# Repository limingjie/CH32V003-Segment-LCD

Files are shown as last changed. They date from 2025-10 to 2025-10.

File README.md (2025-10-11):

# CH32V003 3-Digit 7-Segment LCD Driver

The solution provides an efficient segment LCD driver for the low-cost CH32V003 microcontroller, capable of driving a TN Positive 3-digit 7-Segment LCD using minimal hardware resources and optimized firmware.

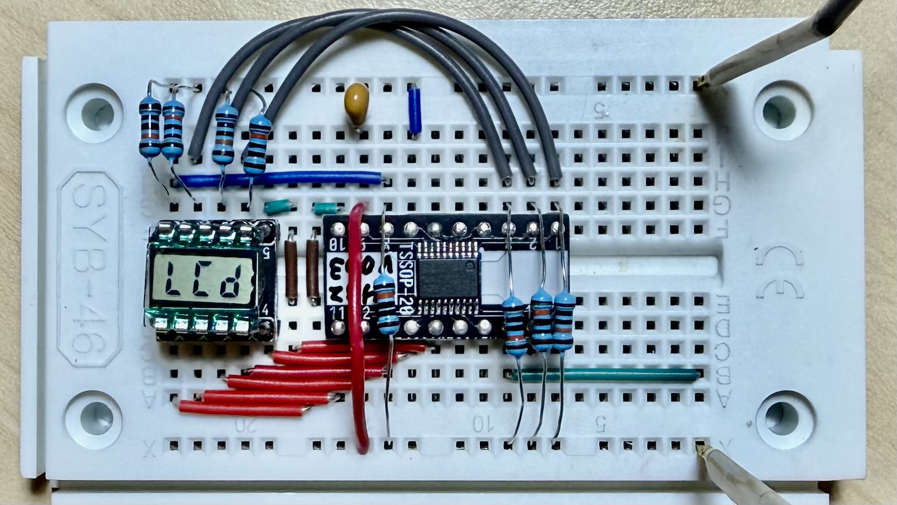
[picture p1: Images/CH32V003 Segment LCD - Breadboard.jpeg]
Breadboard


- [CH32V003 3-Digit 7-Segment LCD Driver](#ch32v003-3-digit-7-segment-lcd-driver)
  - [LCD Control Theory](#lcd-control-theory)
    - [LCD Multiplex](#lcd-multiplex)
    - [LCD Driver Signal and Timing](#lcd-driver-signal-and-timing)
  - [CH32V003 Implementation](#ch32v003-implementation)
    - [Circuit Design and Schematic](#circuit-design-and-schematic)
    - [Character Encoding and Mapping](#character-encoding-and-mapping)
    - [Driver Logic](#driver-logic)
  - [7-Segment Display Characters](#7-segment-display-characters)
  - [Hardware](#hardware)
    - [MCU - CH32V003](#mcu---ch32v003)
    - [TN Positive 3-Digit 7-Segment LCD Panel](#tn-positive-3-digit-7-segment-lcd-panel)
      - [Specifications](#specifications)
  - [References](#references)
  - [License](#license)

## LCD Control Theory

### LCD Multiplex

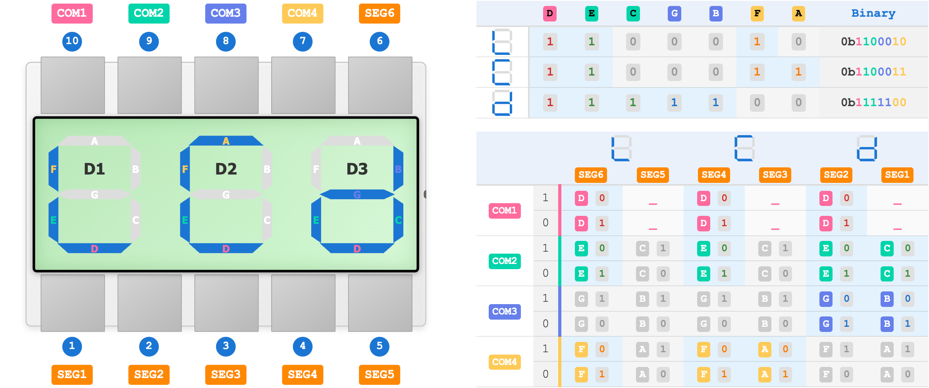
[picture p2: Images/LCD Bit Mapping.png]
LCD Bit Mapping


- Each Common pin controls 1 or 2 segments across 3 characters.
  - **`Common Pin 1`** - **`D`** segments.
  - **`Common Pin 2`** - **`E`** and **`C`** segments.
  - **`Common Pin 3`** - **`G`** and **`B`** segments.
  - **`Common Pin 4`** - **`F`** and **`A`** segments.
- Each Segment pin controls 3 or 4 segments within 1 character.
  - **`D1`** - **`Segment Pin 6`** (**`D`** **`E`** **`G`** **`F`**) and **`Segment Pin 5`** (**`C`** **`B`** **`A`**).
  - **`D2`** - **`Segment Pin 4`** (**`D`** **`E`** **`G`** **`F`**) and **`Segment Pin 3`** (**`C`** **`B`** **`A`**).
  - **`D3`** - **`Segment Pin 2`** (**`D`** **`E`** **`G`** **`F`**) and **`Segment Pin 1`** (**`C`** **`B`** **`A`**).

The wiring diagram of the LCD display (from [Pacific Display](https://www.pacificdisplay.com/lcd_multiplex_drive.htm)).

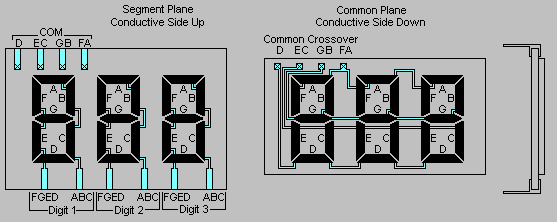
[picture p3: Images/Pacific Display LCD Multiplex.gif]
LCD Multiplex


### LCD Driver Signal and Timing

LCDs use AC signals to prevent damage and ensure longevity by avoiding DC-induced charge accumulation, which can permanently polarize and degrade liquid crystal molecules.

For a `1/2` bias LCD, the Common pins require 3 voltages: `+V`, `+V/2`, and `0`. Use the following timing sequence to ensure the average voltage across the LCD is `0`.

The matrix below shows the voltage difference `SEG - COM` for all possible voltage combinations. The LCD segment is lit when the voltage difference is exactly `±V`.

- LCD segments are **Lit** when `SEG - COM = ±V` for `1/4` duty cycle.
- The voltage difference alternates between positive and negative to maintain AC operation

| **COM Voltages** | **`0` / `LOW`** | **`+V/2` / `FLOAT`** | **`+V`/`HIGH`** |
| :--- | ---: | ---: | ---: |
| **SEG Voltage =  `0` / `LOW`**  | `0` | `-V/2` |  (**Lit**) `-V` |
| **SEG Voltage = `+V` / `HIGH`** |  (**Lit**) `+V` | `+V/2` | `0` |

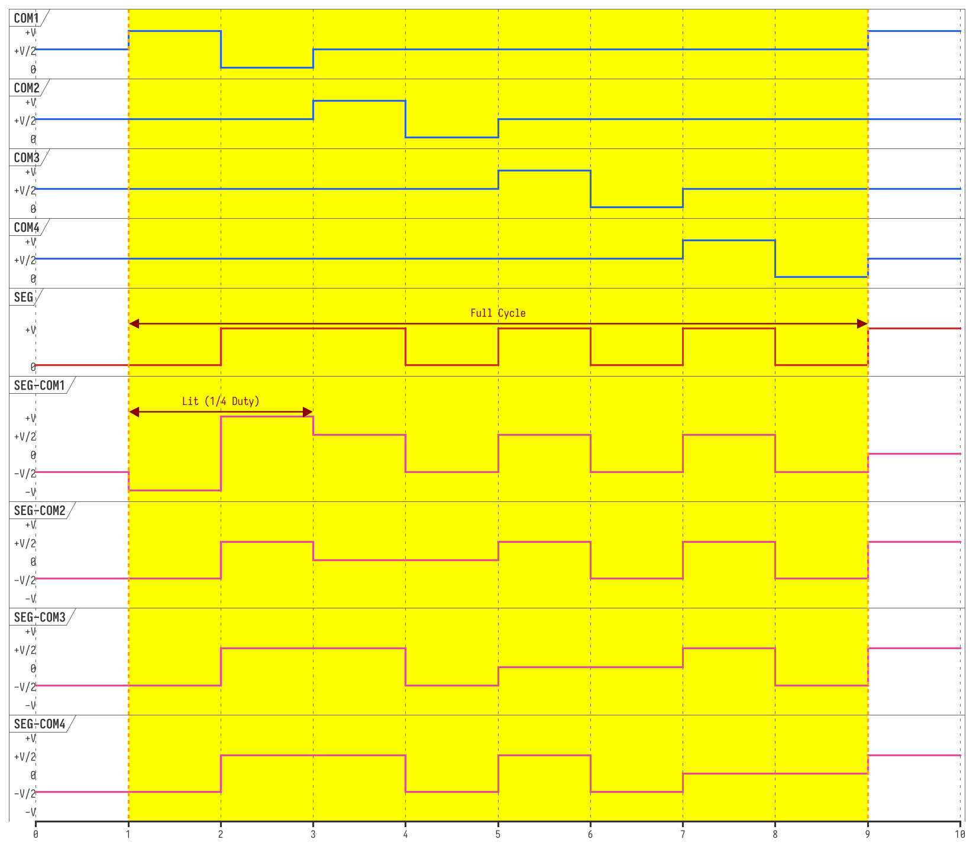
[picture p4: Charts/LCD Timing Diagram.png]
LCD Timing Diagram


## CH32V003 Implementation

### Circuit Design and Schematic

Each Common pin of the LCD is connected to an external voltage divider circuit. When the corresponding GPIO is set to floating input mode, the external voltage divider maintains the Common pin at `+V/2`.

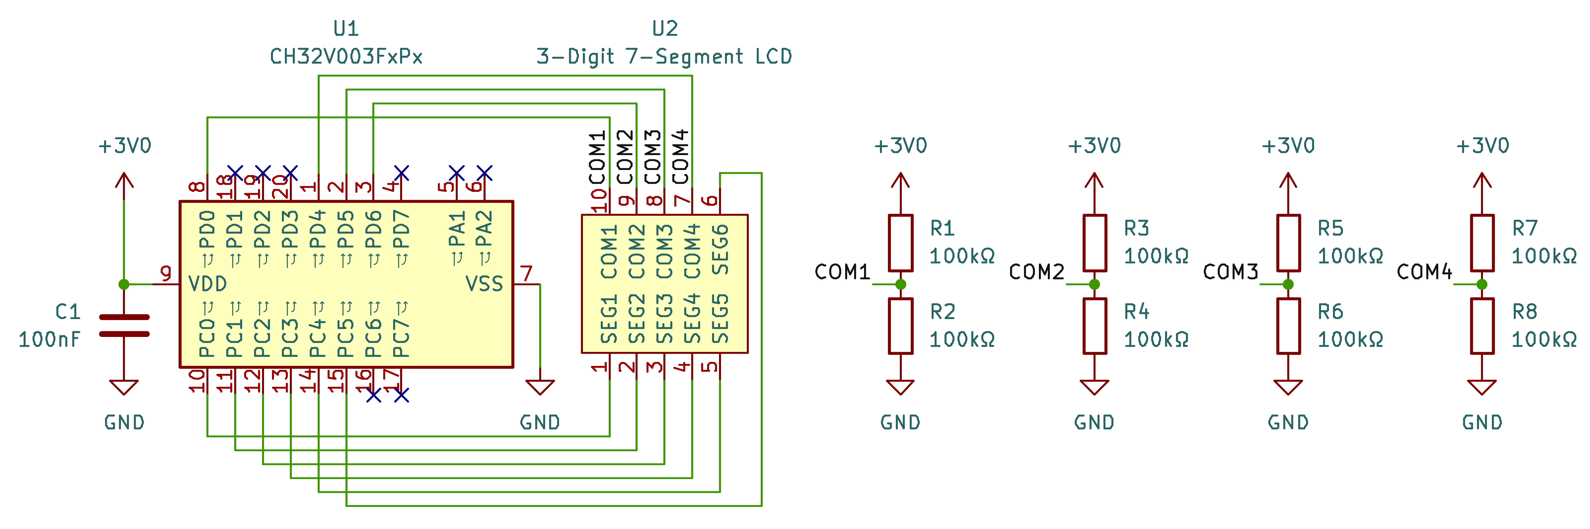
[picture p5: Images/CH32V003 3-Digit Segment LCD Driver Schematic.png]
CH3SchematicV003


### Character Encoding and Mapping

To simplify the 7-segment character to LCD multiplex conversion, the 7-segment character is encoded in **`0b D EC GB FA`**. Actually, any bit order works, keeping **`EC`** **`GB`** **`FA`** groups could simplify the bit operations.

Use the following code to calculate the segment values for each Common pin.

```C
// Convert Character Bit Order (0bDECGBFA) to Segment Masks for Each Common Pin
//                         LCD Char | Seg Group Mask   | <<Shifts>>
//                         D1 D2 D3 | 0bDECGBFA        | D1  D2  D3
// Segment Mask for COM1 - D_ D_ D_ - 0b1000000 / 0x40 - >>1 >>3 >>5
// Segment Mask for COM2 - EC EC EC - 0b0110000 / 0x30 -     >>2 >>4
// Segment Mask for COM3 - GB GB GB - 0b0001100 / 0x0C - <<2     >>2
// Segment Mask for COM4 - FA FA FA - 0b0000011 / 0x03 - <<4 <<2
//              Segments - 65 43 21
seg_masks[0] = ((d1_segs & 0x40) >> 1) | ((d2_segs & 0x40) >> 3) | ((d3_segs & 0x40) >> 5);  // COM1: D  bits
seg_masks[1] = ((d1_segs & 0x30) >> 0) | ((d2_segs & 0x30) >> 2) | ((d3_segs & 0x30) >> 4);  // COM2: EC bits
seg_masks[2] = ((d1_segs & 0x0C) << 2) | ((d2_segs & 0x0C) >> 0) | ((d3_segs & 0x0C) >> 2);  // COM3: GB bits
seg_masks[3] = ((d1_segs & 0x03) << 4) | ((d2_segs & 0x03) << 2) | ((d3_segs & 0x03) >> 0);  // COM4: FA bits
```

Instead of setting each pin individually, the segment values can be directly assigned to the entire GPIO port for more efficient operation.

```C
// BSHR upper 16 bits: Reset pins PC5-PC0 where mask bit = 0
// BSHR lower 16 bits: Set   pins PC5-PC0 where mask bit = 1
GPIOC->BSHR = ((~seg_masks[i] & 0x3F) << 16) | seg_masks[i];
```

### Driver Logic

For CH32V003, each common pin is pulled up and down by resistors to create `+V/2`, and the timing can be implemented with the following code:

```C
static const uint8_t com_pins[4]  = {PIN_COM1, PIN_COM2, PIN_COM3, PIN_COM4};

...

while (1)
{
    // 1000ms / (4ms x 4) = 62.5 FPS
    for (uint8_t i = 0; i < 4; i++)
    {
        const uint8_t com_pin      = com_pins[i];
        const uint8_t seg_mask     = seg_masks[i];
        const uint8_t inv_seg_mask = ~seg_mask & 0x3F;  // Keep lower 6 bits for PC5-PC0

        // COM - Output
        funPinMode(com_pin, GPIO_Speed_2MHz | GPIO_CNF_OUT_PP);

        // COM - High, SEG1-6 - Low as required
        funDigitalWrite(com_pin, FUN_HIGH);
        GPIOC->BSHR = (seg_mask << 16) | inv_seg_mask;
        Delay_Ms(2);

        // COM - Low, SEG1-6 - High as required
        funDigitalWrite(com_pin, FUN_LOW);
        GPIOC->BSHR = (inv_seg_mask << 16) | seg_mask;
        Delay_Ms(2);

        // COM - Float
        funPinMode(com_pin, GPIO_CNF_IN_FLOATING);
    }
}
```

## 7-Segment Display Characters

The characters are from [Wikipedia: Seven-segment display character representations](https://en.wikipedia.org/wiki/Seven-segment_display_character_representations).

- The letters `K`, `M`, `V`, `W`, and `X` do not have good representation.
- Certain pairs of characters cannot be distinguished.
  - `2` and `Z`
  - `5` and `S`
  - `1` and `I`, on different sides but still look the same.

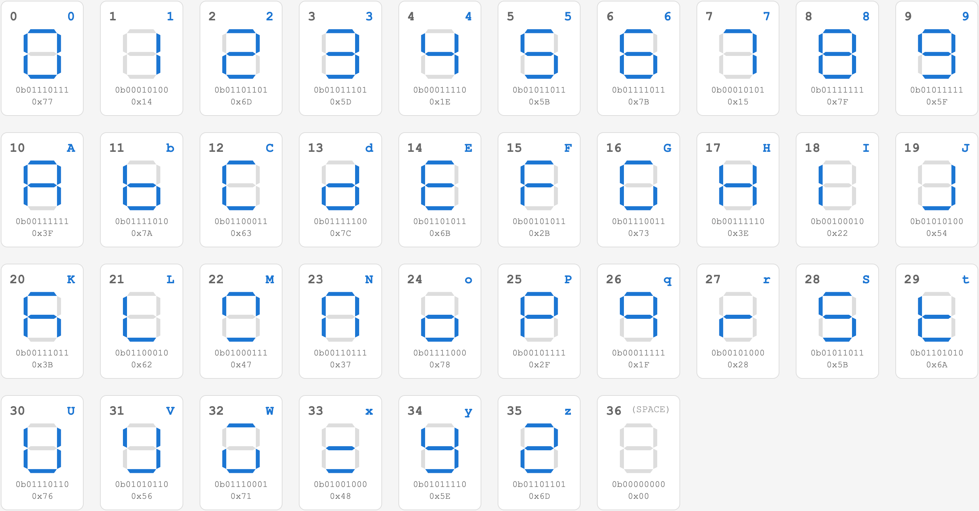
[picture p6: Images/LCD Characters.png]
LCD Characters


## Hardware

### MCU - CH32V003

The CH32V003 is a low-cost, high-performance 32-bit RISC-V microcontroller from WCH. It features a compact design, low power consumption, and a rich set of peripherals, making it ideal for embedded applications and cost-sensitive projects. The CH32V003 supports various interfaces such as UART, SPI, I2C, and PWM, and is well-suited for controlling LED drivers and other hardware components.

- [CH32V003 Datasheet V1.7](./Documents/CH32V003%20Datasheet%20-%20V1.7.PDF)
- [CH32V003 Reference Manual V1.7](./Documents/CH32V003%20Reference%20Manual%20-%20V1.7.PDF)

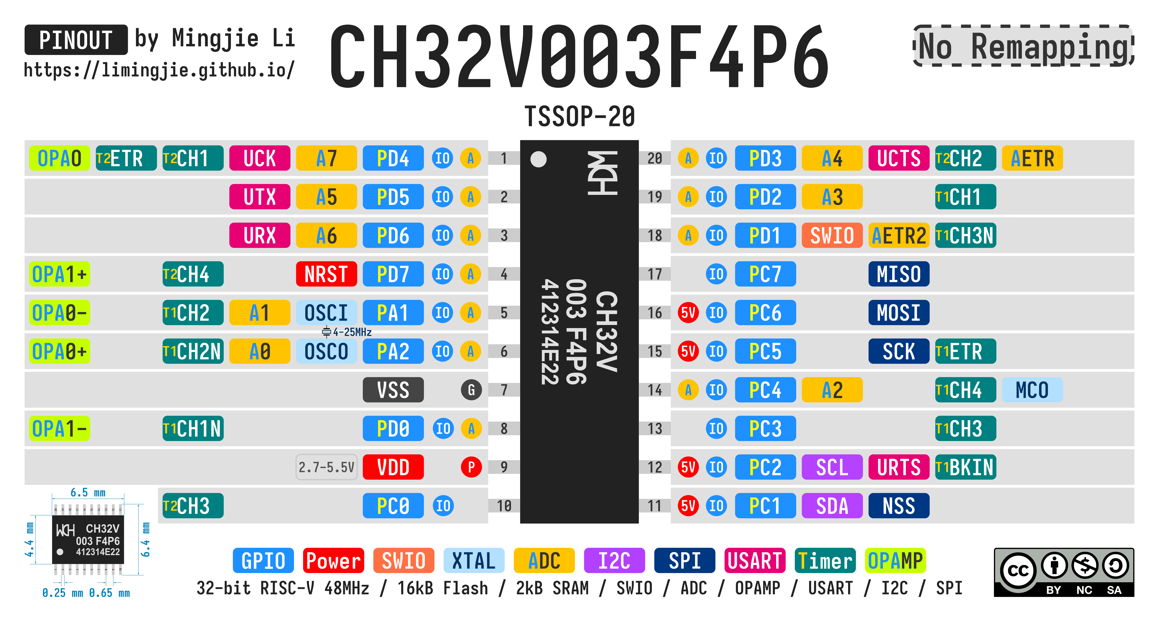
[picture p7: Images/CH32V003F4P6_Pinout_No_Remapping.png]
CH32V003 Pinout


[Link to More CH32V003 Pinout charts](https://github.com/limingjie/WCH-MCU-Pinouts/tree/main/MCU/CH32V)

### TN Positive 3-Digit 7-Segment LCD Panel

I found these LCD panels on [AliExpress](https://www.aliexpress.com/item/1005005697772193.html).

#### Specifications

10-Pin TN Positive 3-Digit 7-Segment LCD Panel, 3.0V Digital Tube Display

1. **Dimensions**: 11.5×10.3/6.3mm, 10 pins, 2 mm pitch
2. **Conductive glass thickness**: 0.7 mm
3. **Minimum pixel gap**: 10 μm
4. **Duty ratio**: 1/4 duty, 1/2 bias
5. **Voltage**: 3.0 V
6. **Operating temperature**: 0°C to +50°C
7. **Viewing direction**: 6 o'clock
8. **Connection method**: Metal pin
9. **TN type viewing range**: 60°, reflective

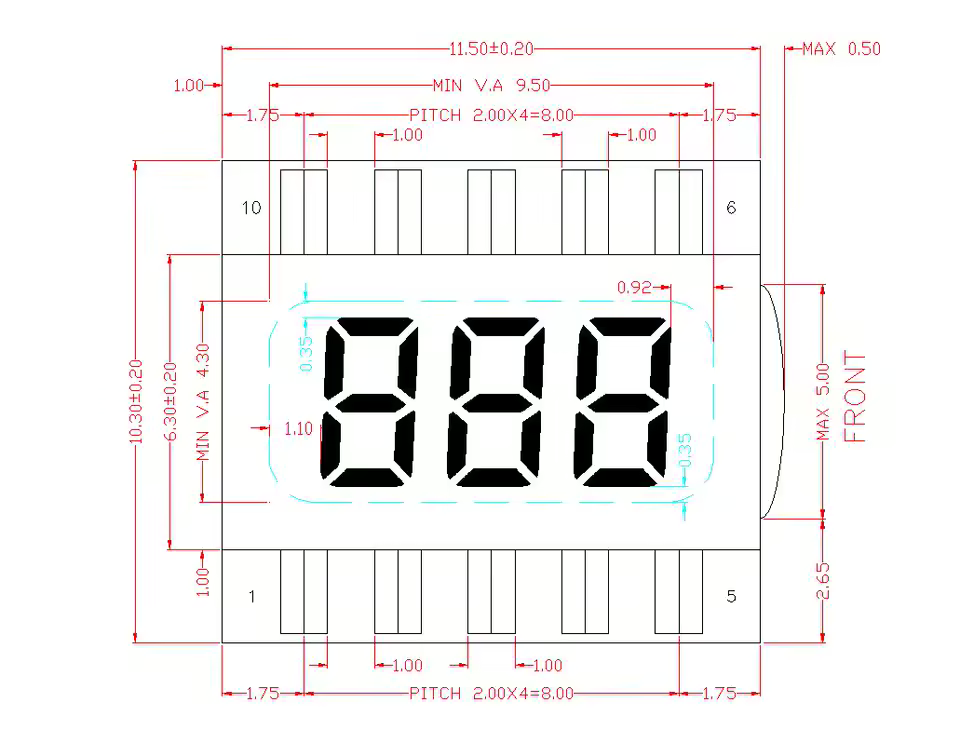
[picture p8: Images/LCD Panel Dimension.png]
LCD Panel Dimension


## References

- [EEVblog #1045 - How To Drive an LCD](https://www.youtube.com/watch?v=ZP0KxZl5N2o)
- [awawa's lab - Direct LCD drive by AVR GPIO](https://awawa.hariko.com/avr_lcd_drive_en.html)
- [LEAP: Little Electronic Art Projects #663 3-Digit LCD Panel](https://github.com/tardate/LittleArduinoProjects/tree/main/Electronics101/Displays/Lcd3Digit)

## License

CC by-nc-sa

This work is licensed under a [Creative Commons Attribution-NonCommercial-ShareAlike 4.0 International License (CC BY-NC-SA 4.0)](https://creativecommons.org/licenses/by-nc-sa/4.0/).

**You are free to:**

- **Share** — copy and redistribute the material in any medium or format
- **Adapt** — remix, transform, and build upon the material

The licensor cannot revoke these freedoms as long as you follow the license terms.

**Under the following terms:**

- **Attribution** - You must give appropriate credit, provide a link to the license, and indicate if changes were made. You may do so in any reasonable manner, but not in any way that suggests the licensor endorses you or your use.
- **NonCommercial** - You may not use the material for commercial purposes.
- **ShareAlike** - If you remix, transform, or build upon the material, you must distribute your contributions under the same license as the original.
- **No additional restrictions** — You may not apply legal terms or technological measures that legally restrict others from doing anything the license permits.

**Notices:**

You do not have to comply with the license for elements of the material in the public domain or where your use is permitted by an applicable exception or limitation.

No warranties are given. The license may not give you all of the permissions necessary for your intended use. For example, other rights such as publicity, privacy, or moral rights may limit how you use the material.

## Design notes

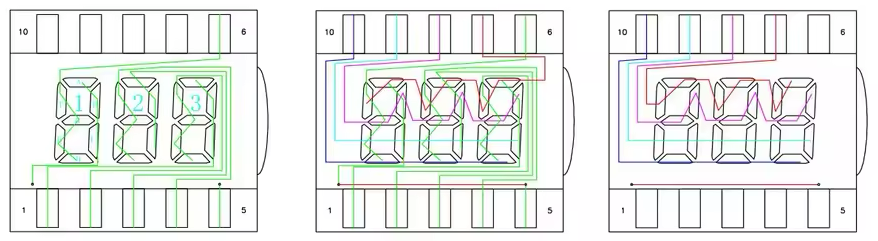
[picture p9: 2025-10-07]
Images/LCD Panel.png

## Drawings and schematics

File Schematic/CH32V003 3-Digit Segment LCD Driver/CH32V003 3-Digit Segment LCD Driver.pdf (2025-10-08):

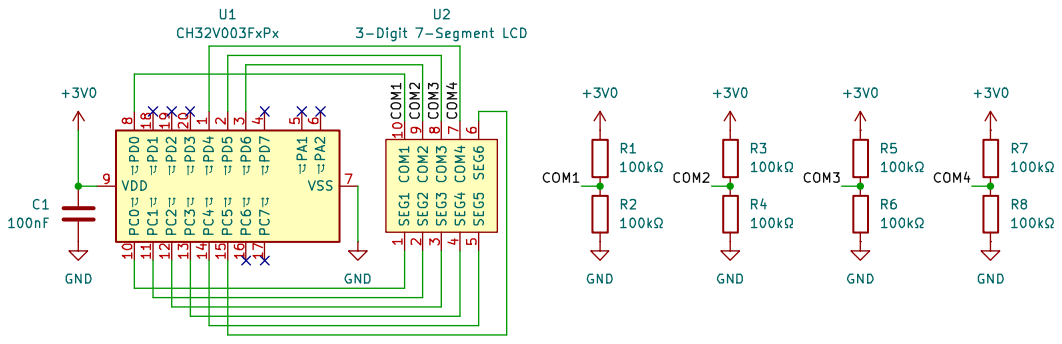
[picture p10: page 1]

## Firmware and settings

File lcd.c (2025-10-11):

/*
 * CH32V003 Segment LCD
 *
 * Oct 2025 by Li Mingjie
 *  - Email:  limingjie@outlook.com
 *  - GitHub: https://github.com/limingjie/
 */

#include "ch32fun.h"

// TN Positive 3-Digit 7-Segment LCD
//
//    LCD PINOUT     |  Segments |  Segment Matrix and CH32V003 Pin Mapping
//                   |           |
//  COM1 2 3 4 SEG6  |           |             PC5  PC4  PC3  PC2  PC1  PC0
//  10 | | | | | 6   |    -A-    |            SEG6 SEG5 SEG4 SEG3 SEG2 SEG1
//    +---------+    |  F|   |B  |  PD0 COM1   1D   __   2D   __   3D   __
//    | D1 D2 D3|    |    -G-    |  PD6 COM2   1E   1C   2E   2C   3E   3C
//    +---------+    |  E|   |C  |  PD5 COM3   1G   1B   2G   2B   3G   3B
//   1 | | | | | 5   |    -D-    |  PD4 COM4   1F   1A   2F   2A   3F   3A
//  SEG1 2 3 4 5     |           |

#define PIN_COM4 PD4
#define PIN_COM3 PD5
#define PIN_COM2 PD6
#define PIN_COM1 PD0
#define PIN_SEG6 PC5
#define PIN_SEG5 PC4
#define PIN_SEG4 PC3
#define PIN_SEG3 PC2
#define PIN_SEG2 PC1
#define PIN_SEG1 PC0

// Segments bit order: 0bDECGBFA
static const uint8_t character_segments[37] = {
    0b1110111,  // 0: ABCDEF_ = 1111110 -> 1110111
    0b0010100,  // 1: _BC____ = 0110000 -> 0010100
    0b1101101,  // 2: AB_DE_G = 1101101 -> 1101101
    0b1011101,  // 3: ABCD__G = 1111001 -> 1011101
    0b0011110,  // 4: _BC__FG = 0110011 -> 0011110
    0b1011011,  // 5: A_CD_FG = 1011011 -> 1011011
    0b1111011,  // 6: A_CDEFG = 1011111 -> 1111011
    0b0010101,  // 7: ABC____ = 1110000 -> 0010101
    0b1111111,  // 8: ABCDEFG = 1111111 -> 1111111
    0b1011111,  // 9: ABCD_FG = 1111011 -> 1011111
    0b0111111,  // A: ABC_EFG = 1110111 -> 0111111
    0b1111010,  // b: __CDEFG = 0011111 -> 1111010
    0b1100011,  // C: A__DEF_ = 1001110 -> 1100011
    0b1111100,  // d: _BCDE_G = 0111101 -> 1111100
    0b1101011,  // E: A__DEFG = 1001111 -> 1101011
    0b0101011,  // F: A___EFG = 1000111 -> 0101011
    0b1110011,  // G: A_CDEF_ = 1011110 -> 1110011
    0b0111110,  // H: _BC_EFG = 0110111 -> 0111110
    0b0100010,  // I: ____EF_ = 0000110 -> 0100010
    0b1010100,  // J: _BCD___ = 0111000 -> 1010100
    0b0111011,  // K: A_C_EFG = 1010111 -> 0111011
    0b1100010,  // L: ___DEF_ = 0001110 -> 1100010
    0b1000111,  // M: AB_D_F_ = 1101010 -> 1000111
    0b0110111,  // N: ABC_EF_ = 1110110 -> 0110111
    0b1111000,  // o: __CDE_G = 0011101 -> 1111000
    0b0101111,  // P: AB__EFG = 1100111 -> 0101111
    0b0011111,  // q: ABC__FG = 1110011 -> 0011111
    0b0101000,  // r: ____E_G = 0000101 -> 0101000
    0b1011011,  // S: A_CD_FG = 1011011 -> 1011011
    0b1101010,  // t: ___DEFG = 0001111 -> 1101010
    0b1110110,  // U: _BCDEF_ = 0111110 -> 1110110
    0b1010110,  // V: _BCD_F_ = 0111010 -> 1010110
    0b1110001,  // W: A_CDE__ = 1011100 -> 1110001
    0b1001000,  // x: ___D__G = 0001001 -> 1001000
    0b1011110,  // y: _BCD_FG = 0111011 -> 1011110
    0b1101101,  // z: AB_DE_G = 1101101 -> 1101101
    0b0000000,  // (space)              -> 0000000
};

static const uint8_t com_pins[4]  = {PIN_COM1, PIN_COM2, PIN_COM3, PIN_COM4};
volatile uint8_t     seg_masks[4] = {0, 0, 0, 0};

void calculate_seg_masks(const uint8_t d1_segs, const uint8_t d2_segs, const uint8_t d3_segs)
{
    // Convert Character Bit Order (0bDECGBFA) to Segment Masks for Each Common Pin
    //                         LCD Char | Seg Group Mask   | <<Shifts>>
    //                         D1 D2 D3 | 0bDECGBFA        | D1  D2  D3
    // Segment Mask for COM1 - D_ D_ D_ - 0b1000000 / 0x40 - >>1 >>3 >>5
    // Segment Mask for COM2 - EC EC EC - 0b0110000 / 0x30 -     >>2 >>4
    // Segment Mask for COM3 - GB GB GB - 0b0001100 / 0x0C - <<2     >>2
    // Segment Mask for COM4 - FA FA FA - 0b0000011 / 0x03 - <<4 <<2
    //              Segments - 65 43 21
    seg_masks[0] = ((d1_segs & 0x40) >> 1) | ((d2_segs & 0x40) >> 3) | ((d3_segs & 0x40) >> 5);  // COM1: D  bits
    seg_masks[1] = ((d1_segs & 0x30) >> 0) | ((d2_segs & 0x30) >> 2) | ((d3_segs & 0x30) >> 4);  // COM2: EC bits
    seg_masks[2] = ((d1_segs & 0x0C) << 2) | ((d2_segs & 0x0C) >> 0) | ((d3_segs & 0x0C) >> 2);  // COM3: GB bits
    seg_masks[3] = ((d1_segs & 0x03) << 4) | ((d2_segs & 0x03) << 2) | ((d3_segs & 0x03) >> 0);  // COM4: FA bits
}

void show_hex_number(const uint16_t number)
{
    calculate_seg_masks(character_segments[(number >> 8) & 0x0F],  // D1
                        character_segments[(number >> 4) & 0x0F],  // D2
                        character_segments[number & 0x0F]);        // D3
}

void show_string(const char* str)
{
    uint8_t segs[3] = {0, 0, 0};  // D1 D2 D3

    for (uint8_t i = 0; i < 3; i++)
    {
        char c = str[i];
        if (c == '\0')
            break;  // Early termination

        // Convert to lowercase
        // - SPC -> 0x20      | 0x20 = 0x20      - Unchanged
        // - 0-9 -> 0x30-0x39 | 0x20 = 0x30-0x39 - Unchanged
        // - A-Z -> 0x41-0x5A | 0x20 = 0x61-0x7A - Converted to lowercase
        // - a-z -> 0x61-0x7A | 0x20 = 0x61-0x7A - Unchanged
        c |= 0x20;

        uint8_t index;
        if (c >= '0' && c <= '9')
        {
            index = c - '0';
        }
        else if (c >= 'a' && c <= 'z')
        {
            index = c - 'a' + 10;
        }
        // segs initialized as spaces
        // else if (c == ' ')
        // {
        //     index = 36;
        // }
        else
        {
            continue;
        }

        segs[i] = character_segments[index];
    }

    calculate_seg_masks(segs[0], segs[1], segs[2]);
}

void systick_init(void)
{
    SysTick->CTLR = 0;
    NVIC_EnableIRQ(SysTicK_IRQn);
    SysTick->CMP  = FUNCONF_SYSTEM_CORE_CLOCK / 1000 * 100 - 1;  // 100ms
    SysTick->CNT  = 0;
    SysTick->CTLR = SYSTICK_CTLR_STE | SYSTICK_CTLR_STIE | SYSTICK_CTLR_STCLK;
}

void SysTick_Handler(void) __attribute__((interrupt));
void SysTick_Handler(void)
{
    // LCDReady  3  2  1  0 Go
    // 01234567890123456789012
    static char*   startup = "LCDReady  3  2  1  0 Go";
    static int16_t counter = -64;

    SysTick->CMP += FUNCONF_SYSTEM_CORE_CLOCK / 1000 * 100;  // 100ms
    SysTick->SR = 0;

    ++counter;
    if (counter < 0)
        show_string(&startup[((counter + 64) >> 3) * 3]);
    else
    {
        counter &= 0xFFF;
        show_hex_number(counter);
    }
}

int main(void)
{
    SystemInit();

    funGpioInitAll();
    // funPinMode(PIN_COM1, GPIO_CNF_IN_FLOATING);
    // funPinMode(PIN_COM2, GPIO_CNF_IN_FLOATING);
    // funPinMode(PIN_COM3, GPIO_CNF_IN_FLOATING);
    // funPinMode(PIN_COM4, GPIO_CNF_IN_FLOATING);
    // funPinMode(PIN_SEG1, GPIO_Speed_2MHz | GPIO_CNF_OUT_PP);
    // funPinMode(PIN_SEG2, GPIO_Speed_2MHz | GPIO_CNF_OUT_PP);
    // funPinMode(PIN_SEG3, GPIO_Speed_2MHz | GPIO_CNF_OUT_PP);
    // funPinMode(PIN_SEG4, GPIO_Speed_2MHz | GPIO_CNF_OUT_PP);
    // funPinMode(PIN_SEG5, GPIO_Speed_2MHz | GPIO_CNF_OUT_PP);
    // funPinMode(PIN_SEG6, GPIO_Speed_2MHz | GPIO_CNF_OUT_PP);
    // funDigitalWrite(PIN_SEG1, FUN_LOW);
    // funDigitalWrite(PIN_SEG2, FUN_LOW);
    // funDigitalWrite(PIN_SEG3, FUN_LOW);
    // funDigitalWrite(PIN_SEG4, FUN_LOW);
    // funDigitalWrite(PIN_SEG5, FUN_LOW);
    // funDigitalWrite(PIN_SEG6, FUN_LOW);

    GPIOD->CFGLR = (GPIOD->CFGLR & 0xF000FFF0) | 0x04440004;  // Set PD0, PD4, PD5, PD6 to floating input
    GPIOC->CFGLR = (GPIOC->CFGLR & 0xFF000000) | 0x00222222;  // Set PC0-PC5 to 2MHz push-pull output
    GPIOC->BSHR  = 0x3F << 16;                                // Set PC0-PC5 to LOW

    systick_init();

    while (1)
    {
        // 1000ms / (4ms x 4) = 62.5 FPS
        for (uint8_t i = 0; i < 4; i++)
        {
            const uint8_t com_pin      = com_pins[i];
            const uint8_t seg_mask     = seg_masks[i];
            const uint8_t inv_seg_mask = ~seg_mask & 0x3F;  // Keep lower 6 bits for PC5-PC0

            // COM - Output
            funPinMode(com_pin, GPIO_Speed_2MHz | GPIO_CNF_OUT_PP);

            // COM - High, SEG1-6 - Low as required
            funDigitalWrite(com_pin, FUN_HIGH);
            GPIOC->BSHR = (seg_mask << 16) | inv_seg_mask;
            Delay_Ms(2);

            // COM - Low, SEG1-6 - High as required
            funDigitalWrite(com_pin, FUN_LOW);
            GPIOC->BSHR = (inv_seg_mask << 16) | seg_mask;
            Delay_Ms(2);

            // COM - Float
            funPinMode(com_pin, GPIO_CNF_IN_FLOATING);
        }
    }
}
